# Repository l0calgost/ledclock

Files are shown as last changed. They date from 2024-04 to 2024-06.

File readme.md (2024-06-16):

LED Clock
<p align="center">
  
  
  
  
</p>

# LED Clock

A customizable 7-segment style Wi-Fi connected clock powered by [WLED](https://github.com/Aircoookie/WLED) and the clock adaption from [imeszaros](https://github.com/imeszaros/ledclock). This repository not only hosts the source code of the firmware but also serves as the documentation of this project providing all necessary files and information to replicate it.

## Overview

The clock has three essential parts: a 3D-printed enclosure, the electronics and the firmware.

**The enclosure** was designed in Fusion 360. 3D printing it requires one color, preferably white. The clock consists of several parts, the biggest part is 126x175x20mm.

**The electronics** are fairly simple: the heart of the project is an ESP32 chip which drives 86 pieces of WS2812b individually addressable LED chips. The LEDs form four 7-segment displays (each segment has three LEDs) and a separator consisting of two LEDs. An USB interface circuitry is also included for easy firmware upgrades.

**The firmware** is powered by the awesome project [WLED](https://github.com/Aircoookie/WLED). It is pre-configured with all the correct parameters, hides all irrelevant settings and features but provides additional functionality specific to this project.

Here are two pictures of the completed project:

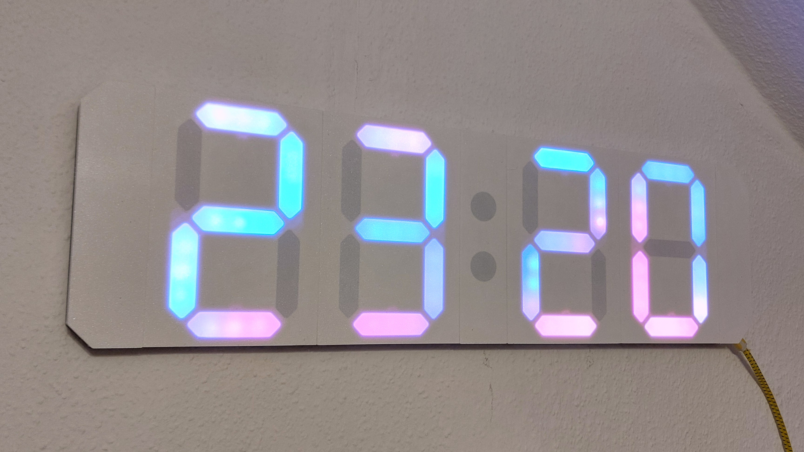
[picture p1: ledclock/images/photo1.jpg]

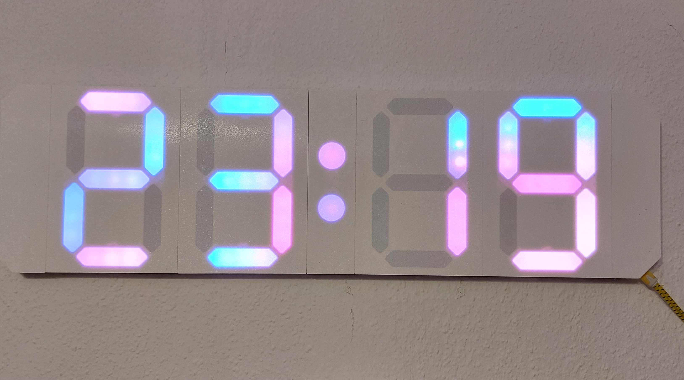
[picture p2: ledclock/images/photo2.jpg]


## Features

- Clock function
    - 12 or 24 hour format
    - automatic time synchronization from the internet
- Timer function
- Stopwatch function
    - Lap time recording
- Control interface available on any device with a browser on the same wireless network
- Android, iPhone, iPad applications (provided by the [WLED](https://github.com/Aircoookie/WLED-App) project)
- Configurable display effects and colors
- Automatic brightness control based on ambient light intensity
- Configurable beeps

See a couple of shots from the ui (click to enlarge):

[](ledclock/images/screenshot-palette.png)
[](ledclock/images/screenshot-clock.png)
[](ledclock/images/screenshot-timer.png)
[](ledclock/images/screenshot-stopwatch.png)

## How to use

Please check the [user's guide](/ledclock/users-guide.md) to get an overview of the features and settings. You may also check the [WLED knowledgebase](https://kno.wled.ge/) for further information.

## Would you like to make it?

This repository has all information you need to make this project:

- [CAD plans for the enclosure](/ledclock/models/cad/)
- [3MF files to 3D print it](/ledclock/models/3d-print/)
- [Schematic and PCB design](/ledclock/sch-pcb/)
- [Gerber files for PCB production](/ledclock/gerber/)
- [Bill of materials](/ledclock/bill-of-materials.md)
- [Assembly insctructions](/ledclock/assembly-guide.md)

## Do you like it?

Do you need help? Have you built the clock? Feel free to [contact me](https://github.com/l0calgost).

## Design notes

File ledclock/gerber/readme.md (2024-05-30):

# Gerber files

All files were created with Kicad. You can order the PCBs simply using these archives.

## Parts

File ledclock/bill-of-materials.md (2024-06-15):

# Bill of Materials

This page lists all parts and materials required to build the clock.

## 3D-printing

Everything can be printed in PLA.

## Electronics

First of all, you need the PCBs. Making them yourself could be quite a challenge since tha main board is a double sided design and the other two boards have a non-square outline which can be best CNC-milled or hand made with a router. Therefore I would recommend ordering them form a prototyping PCB service. I had them made at JLC PCB and the quality they arrived in is very convincing. Check out the [gerber files](gerber/readme.md).

The following table shows the required components. The datasheets show the exact pieces I used in my design and realization.

| Part/Material | Quantity | Notes |
|---|---:|---|
| Power supply | 1 | 5V DC regulated, with at least 3000 mA output current rating.<br>Micro USB connector |
| [WS2812b LED chip](datasheets/ws2812b.pdf) | 86 | |
| Micro USB connector | 1 | |
| Ceramic capacitor 1000uF, 16V, 0603 | 2 | |
| Resistor 330R, 5%, 0603 | 1 | |
| [ESP32-WROOM-32E 4MB](datasheets/esp32-wroom-32e_esp32-wroom-32ue_datasheet_en.pdf) | 1 | See the [pinout](datasheets/esp32-pinout-chip-esp-wroom-32.png). |
| 0.22 mm<sup>2</sup> stranded wire | 58 | 4 distinct colors; quantity is in cm and is for each color separately. |
| M2 6mm screws | 4 | |
| M3 5mm screws | 2 | |
| M3 8mm countersunk head screws | 16 | |
| M3 8mm lens head screws | 22 | 12 are optional if you want to better fix the segments together |
| M3 nuts | 12 | optional if you want to better fix the segments together |

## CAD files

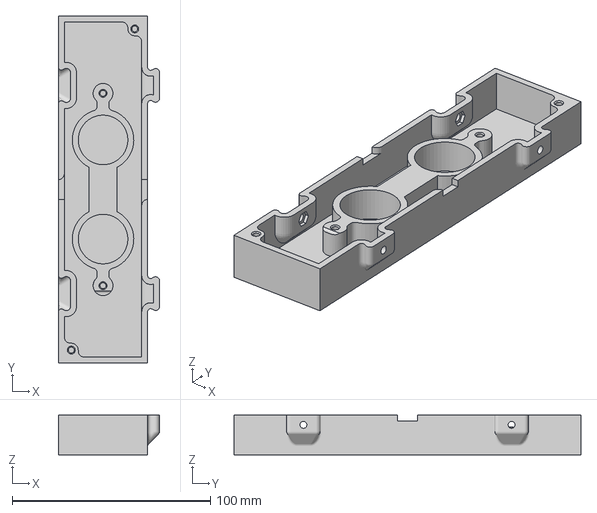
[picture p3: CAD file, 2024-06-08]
ledclock/models/3d-print/Colon_Segment_v54.3mf
51.0 x 175.0 x 20.0 mm

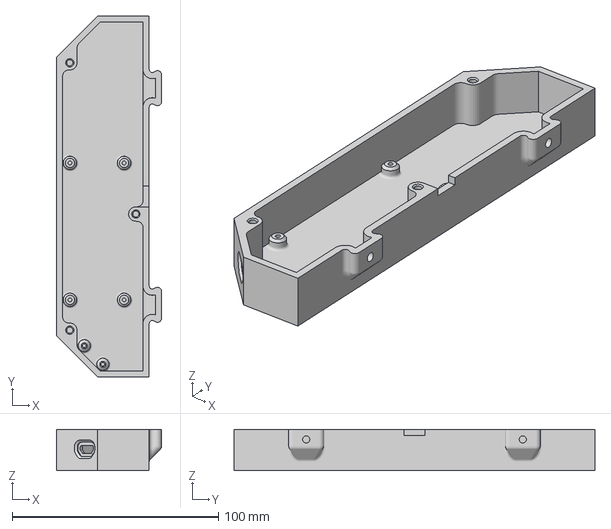
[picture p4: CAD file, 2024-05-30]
ledclock/models/3d-print/Start_Segment_v52.3mf
51.0 x 175.0 x 20.0 mm

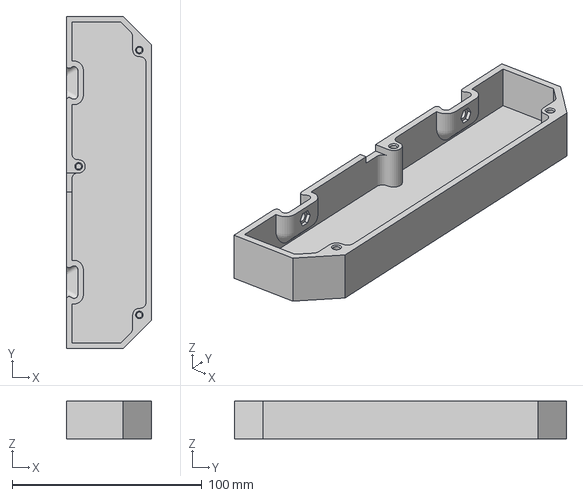
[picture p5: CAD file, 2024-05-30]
ledclock/models/3d-print/End_Segment_v52.3mf
45.0 x 175.0 x 20.0 mm

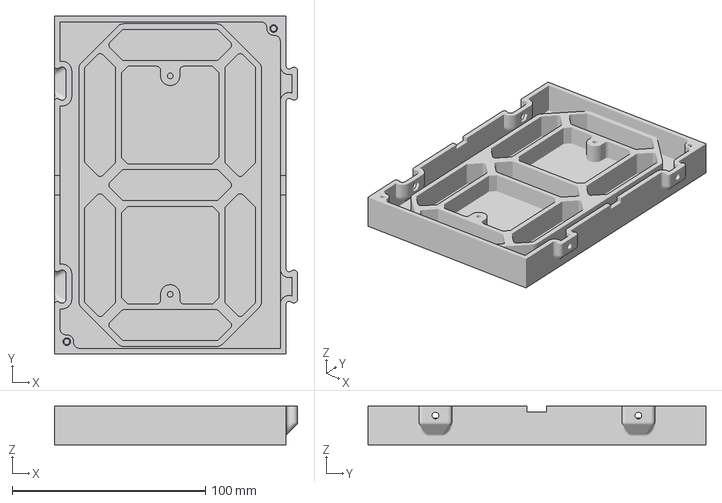
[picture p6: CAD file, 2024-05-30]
ledclock/models/3d-print/Digit_Segment_v52.3mf
126.0 x 174.9 x 20.0 mm

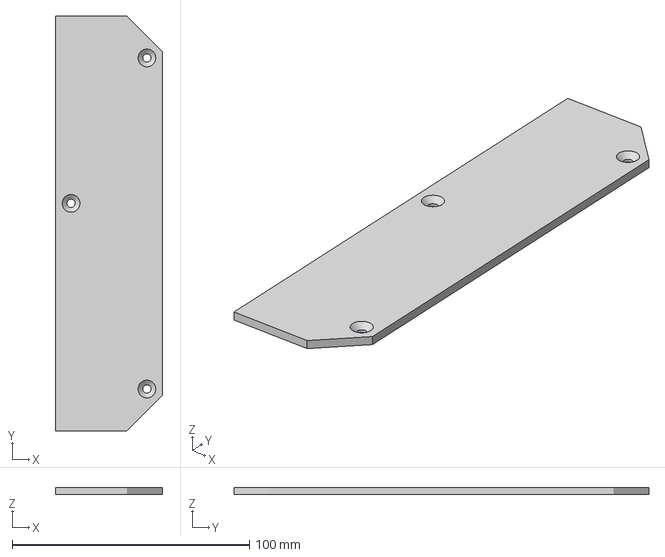
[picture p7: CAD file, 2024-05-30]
ledclock/models/3d-print/End_Segment_Lid_v52.3mf
45.0 x 175.0 x 3.00 mm

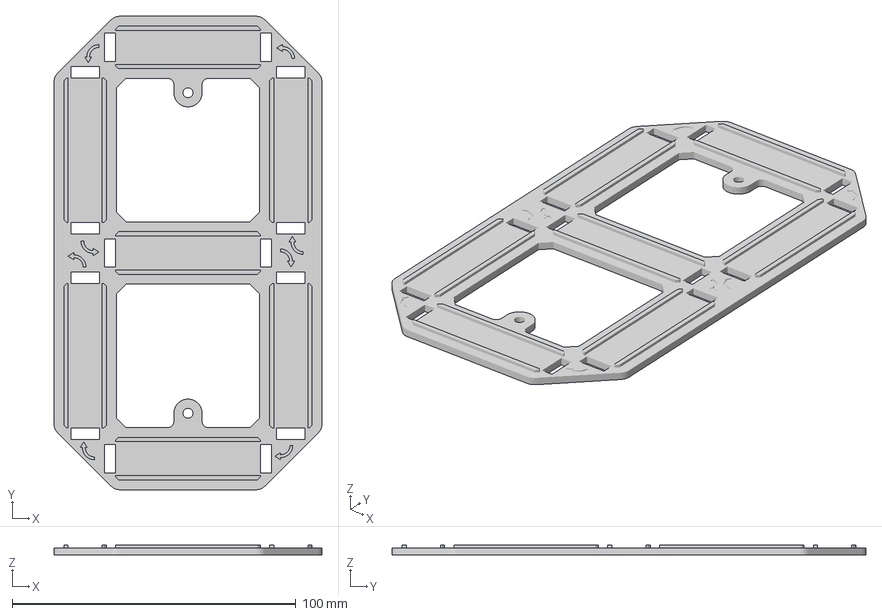
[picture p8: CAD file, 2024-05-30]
ledclock/models/3d-print/Diffusor Lid_v52.3mf
94.5 x 167.0 x 3.50 mm

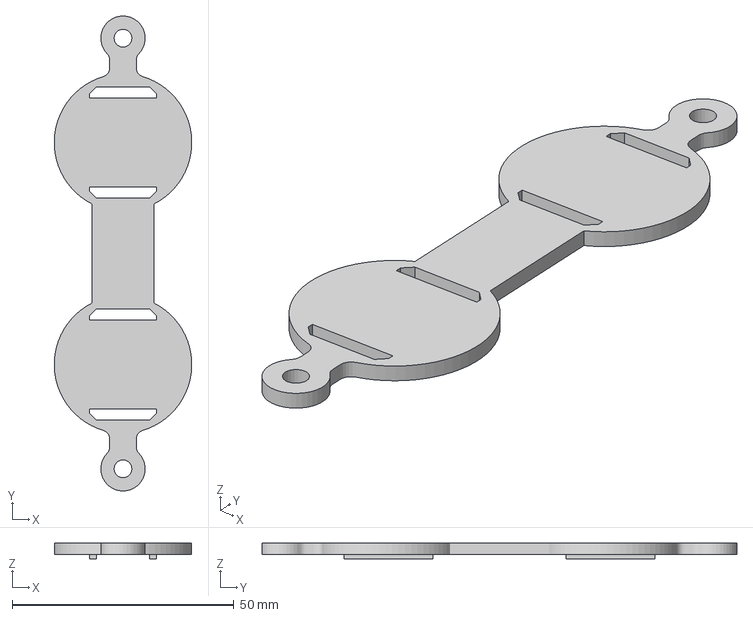
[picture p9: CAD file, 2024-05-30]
ledclock/models/3d-print/Colon_Diffusor_Lid_v52.3mf
31.0 x 107.0 x 3.50 mm

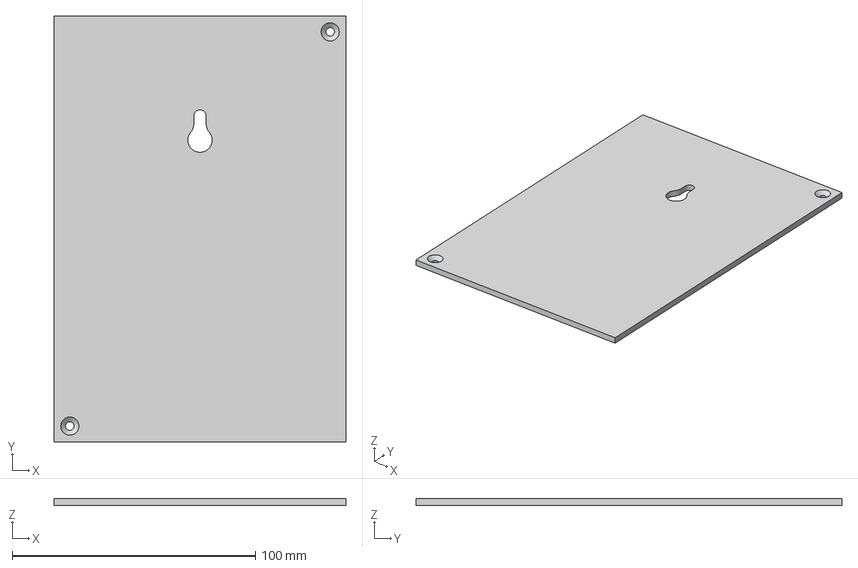
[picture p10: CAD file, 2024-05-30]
ledclock/models/3d-print/Digit_Lid_v52.3mf
120.0 x 175.0 x 3.00 mm

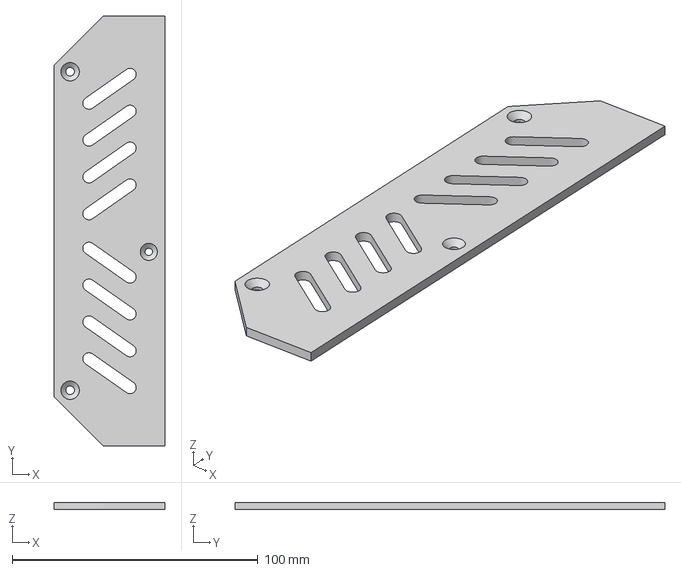
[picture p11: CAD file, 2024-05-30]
ledclock/models/3d-print/Start_Segment_Lid_v52.3mf
45.0 x 175.0 x 3.00 mm

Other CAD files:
ledclock/models/3d-print/Colon_Segment_Lid_v52.3mf

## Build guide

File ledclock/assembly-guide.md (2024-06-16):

# Assembly Guide
This guide describes how to build the clock

- [Assembly Guide](#assembly-guide)
  - [1. Clock Assembly](#1-clock-assembly)
  - [2. LED strip wiring](#2-led-strip-wiring)
  - [3. Final assembly](#3-final-assembly)
  - [4. Integrate electronics](#4-integrate-electronics)
  - [5. Install Software](#5-install-software)

## 1. Clock assembly
Assemble the start, end, digit and colon segments according to the following picture:
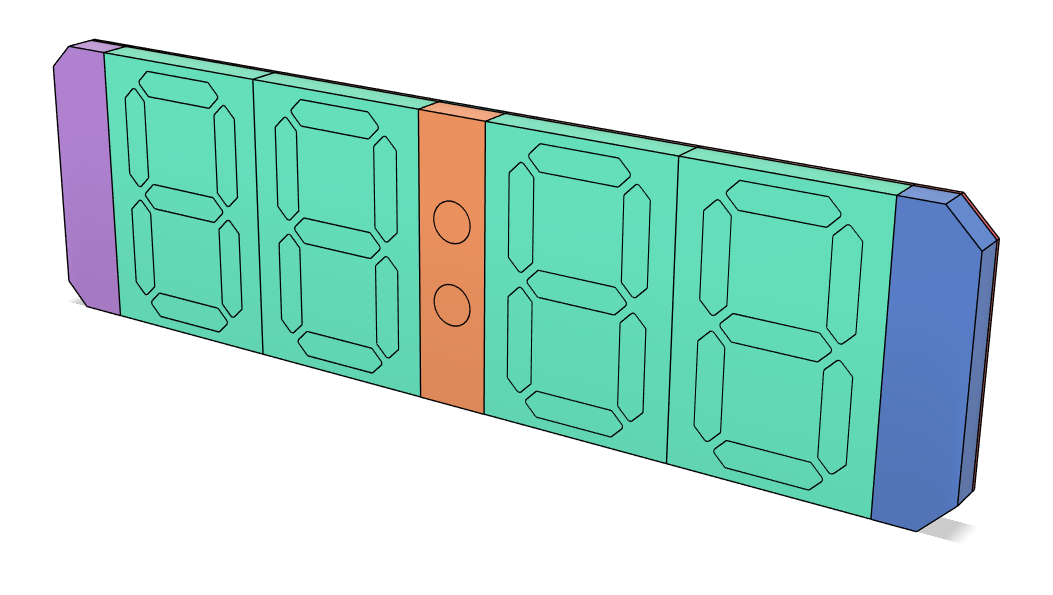
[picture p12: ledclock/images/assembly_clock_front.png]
Assembly clock front

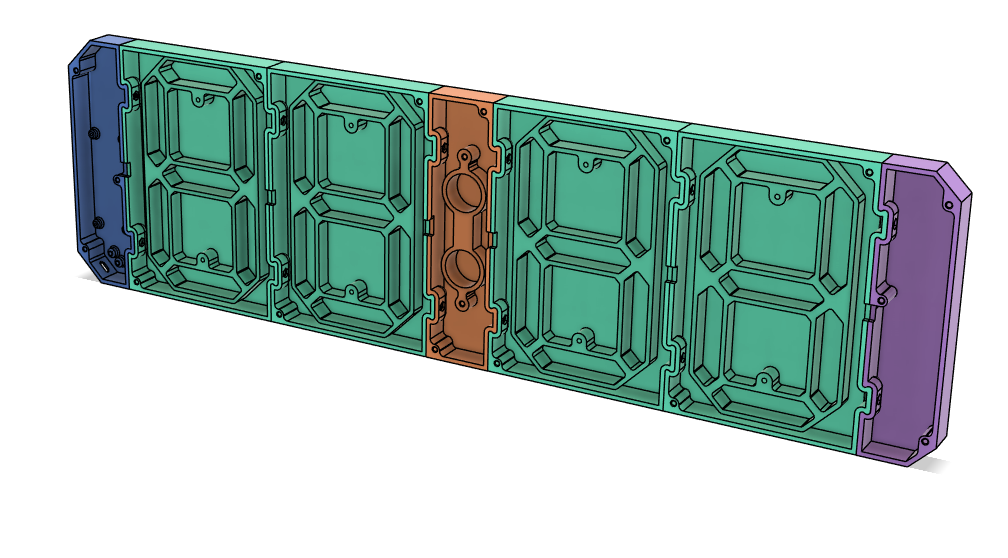
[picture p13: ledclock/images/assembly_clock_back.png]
Assembly clock back


You can optionally secure the segments with the 3x8mm flat head screws and M3 nuts.

## 2. LED strip wiring
Every 7-segment-digit requires three LEDs. Wire the LEDs in the following way. The arrows on the LED holders give additional guidance
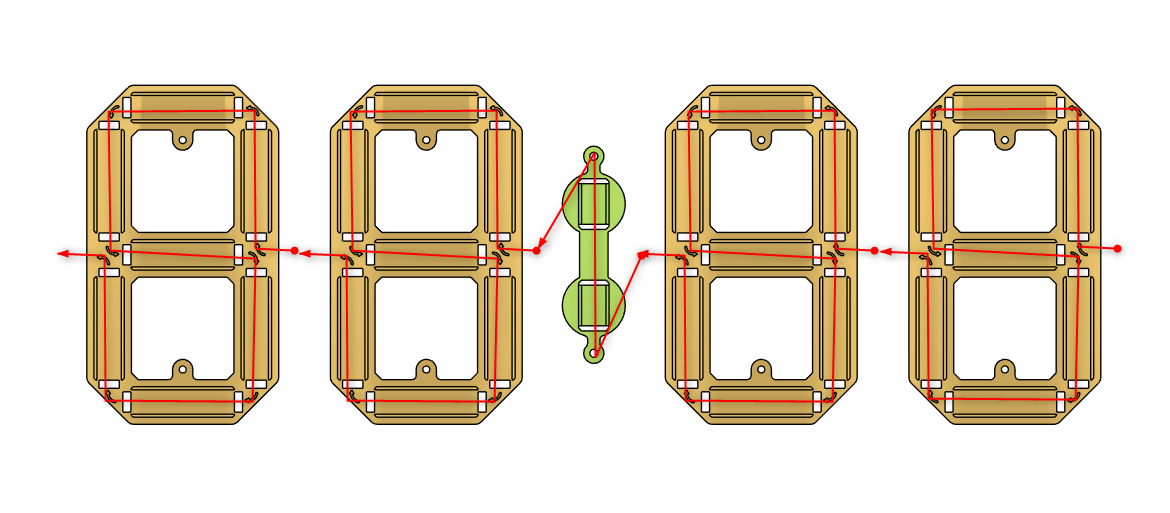
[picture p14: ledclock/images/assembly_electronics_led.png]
Assembly electronics_led


## 3. Final Assembly
Mount the LED holders to the digit and colon segments with M3x8mm flat head screws. Note that this is the view from the back:
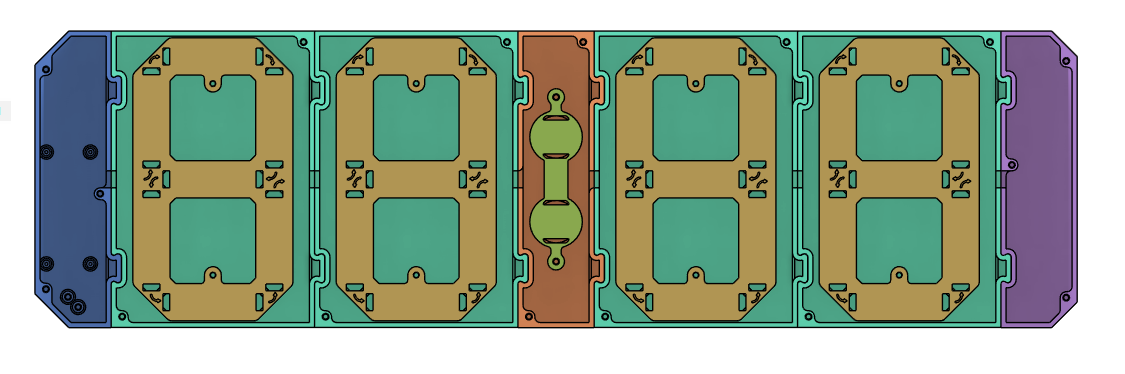
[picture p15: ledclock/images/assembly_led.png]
Assembly led


## 4. Integrate Electronics
Wire the electronics either by ordering the provided PCB or by the following schematics:
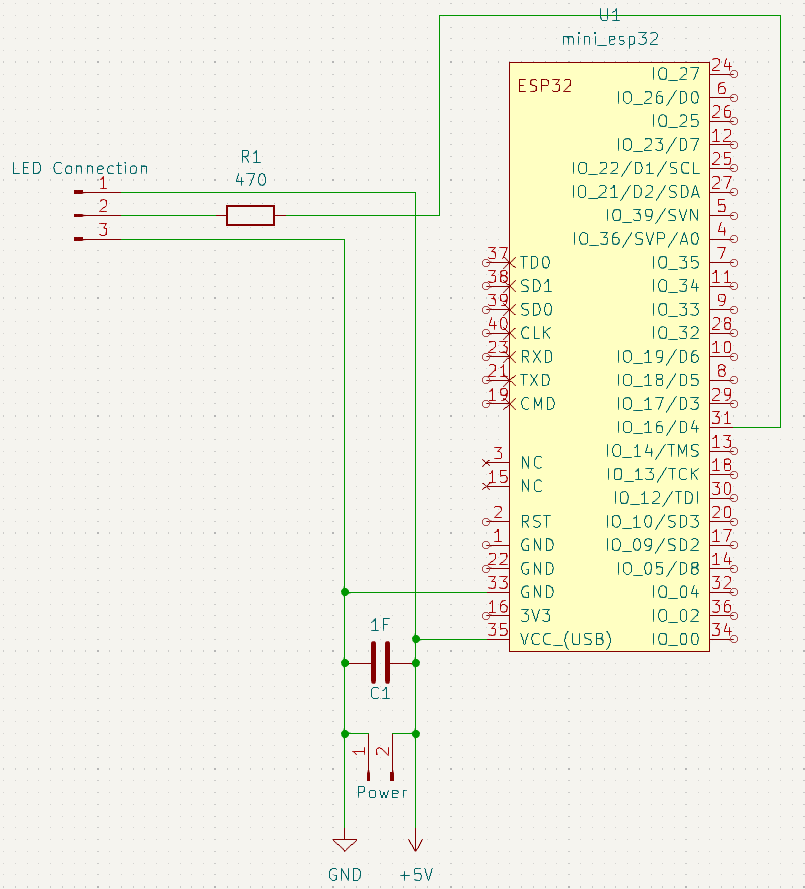
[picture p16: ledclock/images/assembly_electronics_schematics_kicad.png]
Electronics_Wiring


Install the PCB with M2x6 cylinder heat screws and the micro USB board with M3x5 cylinder head screws in the start segment and wire the pcb with the leds:

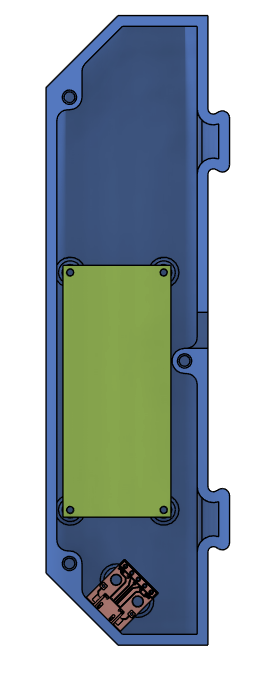
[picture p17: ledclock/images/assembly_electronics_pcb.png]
Assembly led


Close the segments with the back covers and secure them with M3x8 countersunk head screws

## 5. Install Software
Connect the ESP32 via USB and go to [Install](https://l0calgost.github.io/ledclock/) to install the software

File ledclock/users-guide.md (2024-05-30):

# Users guide

This page assumes that you already have the clock fully assembled with the firmware uploaded to it.

- [Users guide](#users-guide)
  - [1. Turning the clock off and on](#1-turning-the-clock-off-and-on)
  - [2. Wi-Fi connection](#2-wi-fi-connection)
  - [3. Using the smartphone application](#3-using-the-smartphone-application)
  - [4. Top buttons](#4-top-buttons)
  - [5. Colors, palettes and effects](#5-colors-palettes-and-effects)
  - [6. Time and time zone settings](#6-time-and-time-zone-settings)
  - [7. Clock features](#7-clock-features)
    - [7.1. Clock](#71-clock)
    - [7.2. Timer](#72-timer)
    - [7.3. Stopwatch](#73-stopwatch)
  - [8. Clock Settings](#8-clock-settings)
    - [8.1. Brightness Control](#81-brightness-control)
    - [8.2. Display Settings](#82-display-settings)
  - [9. Firmware upgrade](#9-firmware-upgrade)
  - [10. Help](#10-help)

## 1. Turning the clock off and on

Simply plug / pull the power cord in / out to turn the clock on and off. The control interface also has a *power toggle* button ([see later](#4-top-buttons)) , but it only controls the state of the clock's display.

## 2. Wi-Fi connection

All configuration of the clock is done via a web interface accessible through a Wi-Fi connection. The clock is not connected to any network by default, instead, it turns itself into a wireless access point named *LED Clock AP*.

You can connect to this access point with any device having a web browser. A pop-up will ask to 'log in' to the wireless network, which in fact will open the control interface of the clock.

At this point you can choose from two options:

- Leave the clock in access point mode. This means that each time you would like to change some settings, you need to connect to the clock again. Automatic time synchronization from the internet wont be possible in this mode (time will be synchronized from the device that connects to the clock instead), neither controlling the clock via the [smartphone application](https://github.com/Aircoookie/WLED-App) provided by WLED.

- Go to the Wi-Fi settings and connect the clock to your home wireless network. This enables automatic time synchronization and smartphone app control. You can control the clock from any device connected to the same network by simply opening a web browser and navigating to the clock's IP address. To connect to your network, simply enter the network name and password, then click on the *Save and Connect* button.

Wi-Fi Settings

## 3. Using the smartphone application

If you chose to connect the clock to your wireless network, you can use the [smartphone application](https://github.com/Aircoookie/WLED-App) provided by the [WLED](https://github.com/Aircoookie/WLED) project.

Obviously you need to install the application first from the Apple/Play store. Launch the app which will present you an empty list of WLED devices. To add the clock to the list, press the *+*  button at the upper-right corner.

Add Device

At the *add* screen you can add the clock manually by entering its IP address, but the app can find it automatically by clicking on the *DISCOVER LIGHTS...* button. After the clock has been found, click on the checkmark button at the upper-right corner.

Discover Lights

The clock should be now visible in the list. Simply tap on it once to bring its control interface up.

Device Selection

This procedure has to be only done once as long as the IP address of the clock remains the same.

## 4. Top buttons

The upmost part of the control interface shows a button bar:

Button Bar

- **Power**: toggles the clock display. Even if the display is turned off, all other functionality of the device continues to work 'in the background'.
- **Clock**: allows access the clock specific features like the timer or stopwatch ([see later](#7-clock-features)).
- **Sync**: if you have multiple WLED based devices in your network you can [synchronize them](https://kno.wled.ge/interfaces/udp-notifier/) to show the same visuals.
- **Peek**: toggles a thin stripe that shows the colors of the display in real time.
- **Info**: shows information about the device and its state.
- **Config**: allows to access various configuration options.

## 5. Colors, palettes and effects

The visuals of the clock display are determined by a **color palette** and an **effect**. The main screen of the control interface allows you to configure these.

On the first tab (Colors) you can select the color palette by choosing it from the many predefined ones or setting up a custom one.

Palettes

To create a custom palette, tap on one of the following buttons:

- Color 1
- Color Gradient
- Colors 1&2
- Colors Only

Depending on your selection, you can specify either 1, 2, or three custom colors. To specify the color, select one of the circular *1*, *2* or *3* buttons and use the color wheel or one of the color preset buttons to set it.

Colors

You can also create completely customized palettes by clicking on the `(+)` button at the bottom of the palette list:

Custom Palettes

This will open a new screen where you can specify the colors and positions of the custom palette.

Displaying numbers or symbols works by masking out the output colors. Since masking means setting the appropriate LEDs to *black*, choosing black or very dark colors, or using certain effects would interfere with the masking and therefore prevent the proper displaying of numbers or symbols on the display.

To fix this, the clock has a special feature called *blending*, also notable on the screenshot above. When blending is enabled, the clock will automatically blend the output colors with a *canvas color* to get a non-black resulting color. This way the masking will work properly and the numbers or symbols will be displayed correctly. Experiment by changing the canvas color and blending modes and see how they affect the output.

To change the effect, go to the second tab (Effects) and choose the desired effect. Most effects have certain settings you can change using the sliders at the bottom of the screen. Note that not all effects are using the current palette. Some effects are using the first and/or second color, or the current palette AND the first and/or second color, etc.

Effects

Feel free to play with the settings to create the visuals you are looking for.

On the third tab (Segments) you may split up the display to multiple segments and apply different visuals to each segment. Check the corresponding [WLED documentation](https://kno.wled.ge/features/segments/) to see how this works.

On the fourth tab (Presets) you can create presets of your favorite settings to load them easier. Read on in the [WLED documentation](https://kno.wled.ge/features/presets/).

## 6. Time and time zone settings

Location: **Config / Time & Macros**

By default, the clock synchronizes itself regularly from the internet when connected to a Wi-Fi network, otherwise from the device where it's controlled from.

You can turn off the synchronization from the internet by removing the tick from the *Get time from NTP server* checkbox. Below you can specify an NTP server for the synchronization.

Yo can also choose 12 or 24 hour display format. To show time matching to your physical location, the correct time zone should be set. The default setting is *CET/CEST*, but it can be also set here.

Time Settings

Don't forget to click on the *Save* button the apply your changes.

## 7. Clock features

Click on the *Clock* button in the top button bur to show the control interface for the clock features. Under *Clock Mode* you can choose the current operational mode of the device.

### 7.1. Clock

In this mode the device shows the current local time. You can click on the buttons for various time / clock related configuration options.

Clock

### 7.2. Timer

In this mode you can set an interval, start the timer and the clock will count down to zero.

Timer

Just tap on one of the drop-downs to set the interval, then tap on *Start* to begin the countdown. You may pause / resume it any time. Clicking on the *Reset* button will stop the countdown and re-sets the original interval. The *+1 Minute* button adds one minute to the remaining time.

### 7.3. Stopwatch

In this mode you can use the clock as a stopwatch.

Stopwatch

Simply hit the *Start* button to start the counting. You may pause / resume it any time. The *Lap Time* button records an intermediate interval showing the elapsed time since the last lap time recording (or since the start of the counting in the case of the first lap time) and the total elapsed time (splits). Clicking on the *Reset* button will stop the counting and zeroes the counter out, clearing all the lap times as well.

## 8. Clock Settings

Location: **Config / Clock Settings**

All LED Clock specific settings can be configured here.

### 8.1. Brightness Control

The device has an ambient light sensor to be able to automatically adjust the brightness of the display, increasing it in bright environments and decreasing it when the light level drops (i.e. at night). This feature is turned on by default, but you can disable it by removing the checkmark:

Brightness Control

You can also set the minimum and maximum brightness levels.

Brightness

### 8.2. Display Settings

You can control whether leading zero should be displayed or not. If the *Hide leading zero (hours)* is checked, hours before 10 will be shown as **8:35** instead of **08:35**.

Display Settings

Behavior of the hour-minute separator can be also changed here by selecting it from the *Hour-minute Separator* drop-down.

Do not forget to tap on the *Save* button to apply your changes.

## 9. Firmware upgrade

No software is perfect. If you encounter any issues or would like to use new functionality added in a later firmware release, you have to upgrade the clock to the latest firmware revision.

To check which version of the firmware you are running, tap on the *Info* button in the top button bar:

Firmware Version

If you need to upgrade, follow the procedure below:

- first download the latest firmware binary from the [releases page](https://github.com/l0calgost/ledclock/releases)
- go to **Config / Security & Updates**
- tap on **Manual OTA Update**
- browse the downloaded firmware binary
- tap on **Update!**
- the update could take around 30-60 seconds, the device will reboot automatically

If you're using the Android app and the version number has not changed following the upgrade, please clear the data of the Android application and re-add your clock to force reloading the new version of the UI.

If for any reason the over-the-air upgrade fails, try the [USB installation method](https://l0calgost.github.io/ledclock/).

## 10. Help

Can't find a solution for your problem on this page? Feel free to [contact me](https://github.com/l0calgost/ledclock).

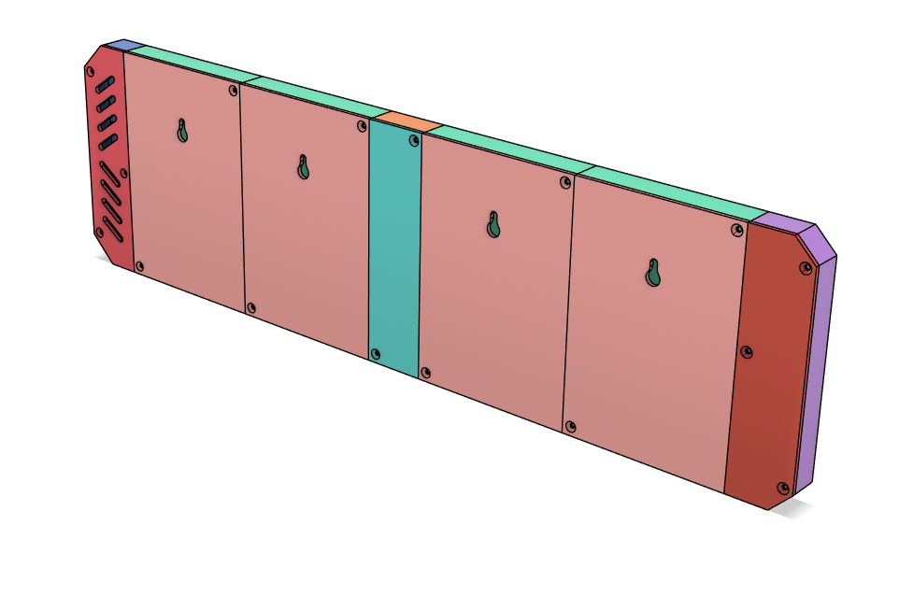
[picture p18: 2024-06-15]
ledclock/images/assembly_clock_covers.png

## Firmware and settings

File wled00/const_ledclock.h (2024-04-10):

#include "inttypes.h"
#include "Arduino.h"

#ifndef WLED_CONST_LEDCLOCK_H
#define WLED_CONST_LEDCLOCK_H

#define MDNS_PREFIX "ledclock"
#define MQTT_DEVICE_TOPIC "ledclock"
#define MQTT_CLIENT_ID "LEDCLOCK"

#define BUZZER_PIN 12
#define ADC_MAX_VALUE 4095
#define ADC_MAX_VOLTAGE 3.3
#define BRIGHTNESS_SAMPLES 1024
#define BRIGHTNESS_THRESHOLD 5
#define BRIGHTNESS_PIN 34

#define STOPWATCH_MAX_LAP_TIMES 100

#define BEEP_SILENT 255

// How to configure the display?
//
// Think of your clock display as 2D matrix of pixels rather than a 7 segment display.
//
// Some pixels of this 2D matrix are missing, others are present. To get the layout
// where the pixels are missing or present, first decide on how many LEDs you want per segment.
//
// For example,  if you have only one LED per segment, the layout is the following:
//
//  -#--#---#--#-
//  #-##-###-##-#
//  -#--#---#--#-
//  #-##-###-##-#
//  -#--#---#--#-
//
// Where the symbol '-' represents a missing pixel and symbol '#' represents a pixel that presents.
// Note the two 'separator' pixels in the middle 'horizontal' column.
//
// If you have 2 LEDs per segment,  the layout is the following:
//
// -##--##---##--##-
// #--##--#-#--##--#
// #--##--###--##--#
// -##--##---##--##-
// #--##--###--##--#
// #--##--#-#--##--#
// -##--##---##--##-
//
// Similarly,  on case of 3 LEDs per segment:
//
// -###--###---###--###-
// #---##---#-#---##---#
// #---##---###---##---#
// #---##---#-#---##---#
// -###--###---###--###-
// #---##---#-#---##---#
// #---##---###---##---#
// #---##---#-#---##---#
// -###--###---###--###-
//
// Next you need to replace all the '-' symbols with -1 and all the '#' symbols with LED indices. Which index
// you write in place of a particular '#' symbol depends on the physical layout of your LED strip.
//
// In the example below there are 2 LEDs per segment, and the LED strip begins with the bottommost segment of
// the first number then continues with the leftmost segments from the bottom to the top. I added extra spaces
// between the numbers and the separator column just for better clarity.

#define LC_LEDS_PER_SEGM 3 // LEDs per segment

#define LC_LEDMAP \
-1, 70, 69, 68, -1,    -1, 49, 48, 47, -1,    -1,    -1, 26, 25, 24, -1,    -1, 5, 4, 3, -1, \
71, -1, -1, -1, 67,    50, -1, -1, -1, 46,    -1,    27, -1, -1, -1, 23,     6, -1, -1, -1, 2, \
72, -1, -1, -1, 66,    51, -1, -1, -1, 45,    -1,    28, -1, -1, -1, 22,     7, -1, -1, -1, 1, \
73, -1, -1, -1, 65,    52, -1, -1, -1, 44,    42,    29, -1, -1, -1, 21,     8, -1, -1, -1, 0, \
-1, 74, 75, 76, -1,    -1, 53, 54, 55, -1,    -1,    -1, 30, 31, 32, -1,    -1, 9, 10, 11, -1, \
85, -1, -1, -1, 77,    64, -1, -1, -1, 56,    43,    41, -1, -1, -1, 33,    20, -1, -1, -1, 12, \
84, -1, -1, -1, 78,    63, -1, -1, -1, 57,    -1,    40, -1, -1, -1, 34,    19, -1, -1, -1, 13, \
83, -1, -1, -1, 79,    62, -1, -1, -1, 58,    -1,    39, -1, -1, -1, 35,    18, -1, -1, -1, 14, \
-1,  82, 81, 80, -1,   -1, 61, 60, 59, -1,    -1,    -1, 38, 37, 36, -1,    -1, 17, 16, 15, -1  \

// Next configure the separator LEDs by first defining how many of them you have:
#define LC_SEP_LEDS 2

// Then write their row indices separated by commas below (notice the separator LEDs #28 and #29 having row indices 2 and 4 in the above LED map):
#define LC_SEP_LED_ROWS 3, 5

// Finally, don't forget to change the total number of LEDs (DEFAULT_LED_COUNT) in `platformio_override.ini`,
// set it to the total size of the LED matrix you have. This number is calculated below and a compiler warning
// is emitted if it does not match with DEFAULT_LED_COUNT.

#define LC_COLS     (((LC_LEDS_PER_SEGM + 2) * 4) + 1)
#define LC_ROWS      ((LC_LEDS_PER_SEGM * 2) + 3)
#define LC_TOTAL_LEDS (LC_COLS * LC_ROWS) // DEFAULT_LED_COUNT should be set to this value

#if !defined(DEFAULT_LED_COUNT) || DEFAULT_LED_COUNT != LC_TOTAL_LEDS
#define LC_XSTR(x) LC_STR(x)
#define LC_STR(x) #x
#pragma message "Macro DEFAULT_LED_COUNT is not defined or is not equal to the calculated number of total LEDs: " LC_XSTR(LC_TOTAL_LEDS)
#endif

// Your display still does not work properly? Verify all the steps above, and if everything looks right, follow these steps:
//   1. navigate your browser http://wled-ip/edit
//   2. right click on /ledmap.json
//   3. choose 'Delete'
//   4. reboot WLED
// The file ledmap.json should now be regenerated with the correct settings and your display should now work properly.


#define LC_PHYSICAL_LEDS (LC_SEP_LEDS + 4 * 7 * LC_LEDS_PER_SEGM)

#define LC_R(c) (byte((c) >> 16))
#define LC_G(c) (byte((c) >> 8))
#define LC_B(c) (byte(c))
#define LC_W(c) (byte((c) >> 24))
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

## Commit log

2024-04-10 adapt led matrix to my layout (3 leds per segment)
2024-05-30 update documentation to custom clock
    [Colon_Diffusor_Lid_v52.3mf, Colon_Segment_Lid_v52.3mf, Colon_Segment_v52.3mf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]
2024-06-08 update colon_segment. It missed the holes to screw it to the digit segments.
    [Colon_Segment_v52.3mf, Colon_Segment_v54.3mf]
2024-06-15 publish 0.2.0 release with led settings enabled
2024-06-15 add assembly manual images
2024-06-15 Add assembly instructions
2024-06-16 add electronics assembly picture
